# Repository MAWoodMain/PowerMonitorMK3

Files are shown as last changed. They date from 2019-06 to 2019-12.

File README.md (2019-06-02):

# Power Meter MK3

## The Plan

The plan is to evaluate the ADE9153 IC using an initial PCB build with mains isolation for easy development and no real planned form factor.

Then assuming the IC checks out the schematic and PCB will be reissued without isolation and with a much tigher form factor to fit in a DIN rail enclosure so it can be wired into my home.

An extra prototype run may be required inbetween to evaluate isolation removal or to fix mistakes that render ISS1 unusable.

The ISS1 PCB is powered from the safe side using a micro USB cable and this power is isolated and used on the hot side, this circuit is based on the ADE9153's evaluation board schematic. 

**It is noteworthy that the hot side's GND is mains live and does present a serious safety risk.**

I accept no liability for anyone else's use of this design.

## PCB Builds

### ISS1 Build:
- PCB ordered from JLC PCB
  - ENIG finish
  - 1.6mm FR4
  - Top side stencil order with the PCB
    - Ordered default size, this was a mistake next time order a custom side much smaller
- Parts ordered from LCSC and DigiKey kitting for 2 PCBs
  - DHL on behalf of Digikey charged excessive customs charges inflating the build cost greatly I recommend Mouser as an alternative (for the UK) and have upissued the BOM accordingly
- Assembled at home
  - Boards were cleaned with IPA
  - Scrap PCBs were used to position the new PCB in place for stenciling
  - Paste was squeegeed onto the boards using a scrap piece of ceramic with a very flat edge
  - All components were hand placed with tweezers
  - The board was placed on a temperature controlled hotplate at 150°C
  - Once the board was evenly preheated (confirmed with IR thermometer) 350°C hot air was used to reflow the components
  - Some joints were not fully reflowed so touchups were performed with a fine soldering tip and extra liquid flux
  - The ADE9153 IC is in a QFN package which is difficult to manage as a hobbiest so reflow did yield some shorts on the edges, the shorts were manually reworked with extra flux and a fine tip.
  - Fortunatly the guard trace around the VAMS did not short to GND or VAMS, the layout recommendations from AD were to expose copper under the QFN which posed a high risk of soldering shorts.
  - The board was then cleaned with flux clean and IPA
  - All hand soldered components were soldered normally
  - A final clean was performed with flux clean
  
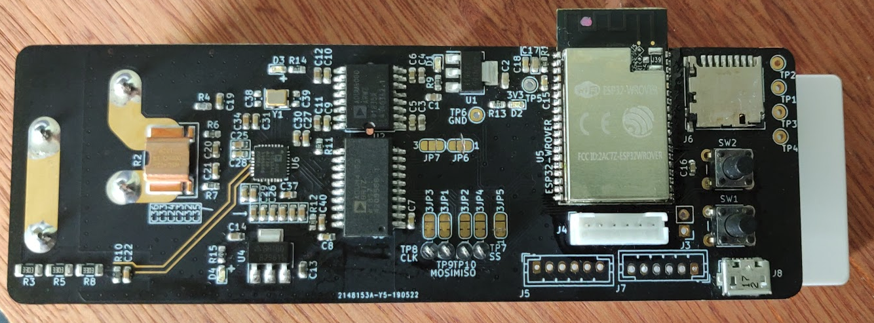
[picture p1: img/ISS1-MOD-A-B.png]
ISS1 Build


#### Issues associated with this build:
[#1](/../../issues/1) [#2](/../../issues/2) [#3](/../../issues/3)
#### Board mods:
- **MOD A** 
  - Pin 5 of U2 (Isolated DC-DC) has to be isolated, the PCB connects it to GND which prevents the IC from working
     - I cut the leg off the IC to isolate it

- **MOD B** 
  - ESP32-Wrover pins 17-22 cannot be used as they are used internally
     - I cut NC jumpers JP5, JP6 & JP7, the both sides of all three jumpers is reserved for internal use so manual wire mods will be needed lated to connect these to appropriate pins

## Firmware development

Currently in hardware testing phase, temporary non VCS projects are being used to evaluate the PCB, once this process is complete a formal firmware project will be added to VCS and developed

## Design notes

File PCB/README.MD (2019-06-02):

# Power Monitor MK3 PCB

## Outstanding Issues

- [ ] [#1](/../../issues/1) Copper pour sticks out of board edge
- [ ] [#2](/../../issues/2) U2's Pin 5 shorted to GND should be NC
- [ ] [#3](/../../issues/3) Reserved pins being used on JP5, JP6 & JP7
- [ ] Silkscreen is uninformative
- [ ] Power LEDs on all rails is annoying and not very useful after the initial power on test
- [ ] No LED to blink from the ESP?
- [ ] No test points on the mains side (was intentional because GND is 240Vac over there :grimacing:)
- [ ] Add CH340G or equivilent USB to UART with auto GPIO0 & RST for toolless development

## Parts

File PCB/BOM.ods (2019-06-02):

Reference | Quantity | Value | Footprint | Already Have | Supplier | PN & link | Mfr PN | Price/unit @ Q | MOQ | Total price | Cost
C11 C4 C3 C12 C13 C1 | 6 | 10uF | Capacitor_SMD:C_0603_1608Metric | NO | LCSC | C92487 (https://lcsc.com/product-detail/Multilayer-Ceramic-Capacitors-MLCC-SMD-SMT_SAMSUNG_CL10A106MO8NQNC_10uF-106-20-16V_C92487.html) | CL10A106MO8NQNC | $0.0340 | 10 | $0.34 | $0.34
C14 C2 C17 | 3 | 22uF | Capacitor_SMD:C_0603_1608Metric | NO | LCSC | C86295 (https://lcsc.com/product-detail/Multilayer-Ceramic-Capacitors-MLCC-SMD-SMT_SAMSUNG_CL10A226MP8NUNE_22uF-226-20-10V_C86295.html) | CL10A226MP8NUNE | $0.0230 | 20 | $0.46 | $0.46
C22 | 1 | 15nF | Capacitor_SMD:C_0603_1608Metric | NO | LCSC | C296713 (https://lcsc.com/product-detail/Others_Samsung-Electro-Mechanics_CL10B153KB8NNNC_Samsung-Electro-Mechanics-CL10B153KB8NNNC_C296713.html) | CL10B153KB8NNNC | $0.0058 | 50 | $0.29 | $0.29
C36 C35 C27 C34 C26 C25 C23 | 7 | 4.7uF | Capacitor_SMD:C_0603_1608Metric | NO | LCSC | C69335 (https://lcsc.com/product-detail/Multilayer-Ceramic-Capacitors-MLCC-SMD-SMT_SAMSUNG_CL10A475KA8NQNC_4-7uF-475-10-25V_C69335.html) | CL10A475KA8NQNC | $0.0303 | 20 | $0.61 | $0.61
C37 | 1 | 470nF | Capacitor_SMD:C_0603_1608Metric | NO | LCSC | C318652 (https://lcsc.com/product-detail/Others_Samsung-Electro-Mechanics_CL10F474ZO8NNNC_Samsung-Electro-Mechanics-CL10F474ZO8NNNC_C318652.html) | CL10F474ZO8NNNC | $0.0081 | 50 | $0.41 | $0.41
C39 C38 | 2 | 30pF | Capacitor_SMD:C_0603_1608Metric | NO | LCSC | C22397 (https://lcsc.com/product-detail/Multilayer-Ceramic-Capacitors-MLCC-SMD-SMT_SAMSUNG_CL10C300JB8NNNC_30pF-300-5-50V_C22397.html) | CL10C300JB8NNNC | $0.0053 | 50 | $0.27 | $0.27
C40 | 1 | 1uF | Capacitor_SMD:C_0603_1608Metric | NO | LCSC | C59782 (https://lcsc.com/product-detail/Multilayer-Ceramic-Capacitors-MLCC-SMD-SMT_SAMSUNG_CL10B105KO8NNNC_1uF-105-10-16V_C59782.html) | CL10B105KO8NNNC | $0.0065 | 50 | $0.33 | $0.33
C9 C6 C5 C10 C7 C8 C18 C15 C16 C33 C32 C31 C30 C29 C28 C20 C21 C19 C24 | 19 | 100nF | Capacitor_SMD:C_0603_1608Metric | NO | LCSC | C1590 (https://lcsc.com/product-detail/Multilayer-Ceramic-Capacitors-MLCC-SMD-SMT_SAMSUNG_CL10B104KA8NNNC_100nF-104-10-25V_C1590.html) | CL10B104KA8NNNC | $0.0057 | 50 | $0.29 | $0.29
D4 D3 D2 D1 | 4 | LED | LED_SMD:LED_0603_1608Metric | NO | LCSC | C205443 (https://lcsc.com/product-detail/Light-Emitting-Diodes-LED_0603-green_C205443.html) | ORH-G36G | $0.0096 | 50 | $0.48 | $0.48
J1 J2 | 2 | MAINS_OUT & MAINS_IN | 1792229:PHOENIX_1792229 | NO | Mouser | 651-1792229 (https://www.mouser.co.uk/ProductDetail/Phoenix-Contact/1792229) | 1792229 | $4.2600 | 1 | $8.52 | $8.52
J3 | 1 | ESP32_BOOT | Connector_PinHeader_2.54mm:PinHeader_1x02_P2.54mm_Vertical | YES | LCSC | C132504 (https://lcsc.com/product-detail/Wire-To-Board-Wire-To-Wire-Connector_Shenzhen-Cankemeng-2510S-2P_C132504.html) | 2510S-2P | $0.0102 | 50 | $0.51 | $0.00
J5 J4 J7 | 2 | ESP_JTAG | Connector_JST:JST_PH_B6B-PH-K_1x06_P2.00mm_Vertical | NO | LCSC | C33478 (https://lcsc.com/product-detail/Wire-To-Board-Wire-To-Wire-Connector_Boom-Precision-Elec-PH-6A_C33478.html) | PH-6A | $0.0105 | 50 | $0.53 | $0.53
J6 | 1 | Micro_SD_Card | Connector_Card:microSD_HC_Hirose_DM3D-SF | NO | Mouser | 798-DM3D-SF (https://www.mouser.co.uk/ProductDetail/Hirose-Connector/DM3D-SF) | DM3D-SF | $1.5300 | 1 | $1.53 | $1.53
J8 | 1 | USB_B_Micro | Connector_USB:USB_Micro-B_Molex_47346-0001 | NO | LCSC | C132560 (https://lcsc.com/product-detail/USB-Connectors_MOLEX_47346-0001_47346-0001_C132560.html) | 47346-0001 | $0.8320 | 1 | $0.83 | $0.83
R1 | 1 | 100K | Resistor_SMD:R_0603_1608Metric | NO | LCSC | C25803 (https://lcsc.com/product-detail/Chip-Resistor-Surface-Mount_Uniroyal-Elec-0603WAF1003T5E_C25803.html) | 0603WAF1003T5E | $0.0010 | 100 | $0.10 | $0.10
R11 R12 | 2 | 10K | Resistor_SMD:R_0603_1608Metric | NO | LCSC | C25804 (https://lcsc.com/product-detail/Chip-Resistor-Surface-Mount_Uniroyal-Elec-0603WAF1002T5E_C25804.html) | 0603WAF1002T5E | $0.0010 | 100 | $0.10 | $0.10
R14 R9 R10 | 3 | 1K | Resistor_SMD:R_0603_1608Metric | NO | LCSC | C21190 (https://lcsc.com/product-detail/Chip-Resistor-Surface-Mount_Uniroyal-Elec-0603WAF1001T5E_C21190.html) | 0603WAF1001T5E | $0.0008 | 100 | $0.08 | $0.08
R15 R13 | 2 | 220 | Resistor_SMD:R_0603_1608Metric | NO | LCSC | C107696 (https://lcsc.com/product-detail/Chip-Resistor-Surface-Mount_220R-220R-1_C107696.html) | RC0603FR-07220RL | $0.0009 | 100 | $0.09 | $0.09
R2 | 1 | 300u/500u | Project:WSL4026 | NO | Mouser | 71-WSL4026L5000FEB (https://www.mouser.co.uk/ProductDetail/Vishay-Dale/WSL4026L5000FEB) | WSL4026L5000FEB | $2.1700 | 1 | $2.17 | $2.17
R3 R5 R8 | 3 | 330K | Resistor_SMD:R_1206_3216Metric | NO | LCSC | C163390 (https://lcsc.com/product-detail/Chip-Resistor-Surface-Mount_RC1206DR-07330KL_C163390.html) | RC1206DR-07330KL | $0.0112 | 50 | $0.56 | $0.56
R4 | 1 | 0 | Resistor_SMD:R_0603_1608Metric | NO | LCSC | C163836 (https://lcsc.com/product-detail/Chip-Resistor-Surface-Mount_Walsin-Tech-Corp-WR06X0000FTL_C163836.html) | WR06X0000FTL | $0.0008 | 100 | $0.08 | $0.08
R6 R7 | 2 | 150K | Resistor_SMD:R_0603_1608Metric | NO | LCSC | C294649 (https://lcsc.com/product-detail/Others_Guangdong-Fenghua-Advanced-Tech-RS-03K1503FT_C294649.html) | RS-03K1503FT | $0.0010 | 100 | $0.10 | $0.10
SW1 SW2 | 1 | BOOT_SW | Button_Switch_THT:SW_PUSH_6mm | YES | LCSC | C294501 (https://lcsc.com/product-detail/Tactile-Switches_BRIGHT-TSA061G50-250_C294501.html) | TSA061G50-250 | $0.0193 | 20 | $0.39 | $0.00
TP1 TP2 TP3 TP4 TP5 TP6 TP7 TP8 TP9 TP10 | 10 | Several | Connector_Pin:Pin_D1.0mm_L10.0mm | NO | LCSC | C238122 (https://lcsc.com/product-detail/Test-Points-Test-Rings_Keystone_5001_Keystone-5001_C238122.html) | 5001 | $0.2402 | 1 | $2.40 | $2.40
U2 | 1 | ADuM6000 | Package_SO:SOIC-16W_7.5x10.3mm_P1.27mm | NO | Mouser | 584-ADUM6000ARWZ (https://www.mouser.co.uk/ProductDetail/Analog-Devices-Linear-Technology/ADUM6000ARWZ) | ADUM6000ARWZ | $8.6100 | 1 | $8.61 | $8.61
U3 | 1 | ADuM4152BRIZ | Package_SO:SOIC-20W_7.5x12.8mm_P1.27mm | NO | Mouser | 584-ADUM4152BRIZ (https://www.mouser.co.uk/ProductDetail/Analog-Devices/ADUM4152BRIZ) | ADUM4152BRIZ | $9.4800 | 1 | $9.48 | $9.48
U4 U1 | 2 | AZ1117-3.3 | Package_TO_SOT_SMD:SOT-223-3_TabPin2 | NO | LCSC | C92102 (https://lcsc.com/product-detail/Low-Dropout-Regulators-LDO_DIODES_AZ1117CH-3-3TRG1_AZ1117CH-3-3TRG1_C92102.html) | AZ1117CH-3.3TRG1 | $0.0677 | 5 | $0.34 | $0.34
U5 | 1 | ESP32-WROVER-B_(16MB) | ESP32-WROVER-B__16MB_:XCVR_ESP32-WROVER-B_(16MB) | NO | Mouser | 356-ESP32-WROB(16MB) (https://www.mouser.co.uk/ProductDetail/Espressif-Systems/ESP32-WROVER-B-16MB) | ESP32-WROVER (16MB) | $4.8300 | 1 | $4.83 | $4.83
U6 | 1 | ADE9153A | Package_DFN_QFN:QFN-32-1EP_5x5mm_P0.5mm_EP3.1x3.1mm | NO | Mouser | 584-ADE9153AACPZ (https://www.mouser.co.uk/ProductDetail/Analog-Devices/ADE9153AACPZ) | ADE9153AACPZ | $6.3800 | 1 | $6.38 | $6.38
Y1 | 1 | 12.288MHz 18pF | Crystal:Crystal_SMD_3225-4Pin_3.2x2.5mm | NO | LCSC | C24117 (https://lcsc.com/product-detail/SMD-Oscillators-XO_EPSON_Q33310F70062000_SG-310SCF-12-288MHZ-3-3V-40-85_C24117.html) | Q33310F70062000 | $0.6968 | 1 | $0.70 | $0.70
 |  |  |  |  |  |  |  |  |  | $51.78 | $50.88

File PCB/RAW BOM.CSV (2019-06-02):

Reference | Quantity | Value | Footprint | Datasheet | Field4 | Field5 | Field6 | Field7 | Field8
C11 C4 C3 C12 C13 C1 | 6 | 10uF | Capacitor_SMD:C_0603_1608Metric | ~
C14 C2 C17 | 3 | 22uF | Capacitor_SMD:C_0603_1608Metric | ~
C22 | 1 | 15nF | Capacitor_SMD:C_0603_1608Metric | ~
C36 C35 C27 C34 C26 C25 C23 | 7 | 4.7uF | Capacitor_SMD:C_0603_1608Metric | ~
C37 | 1 | 470nF | Capacitor_SMD:C_0603_1608Metric | ~
C39 C38 | 2 | 30pF | Capacitor_SMD:C_0603_1608Metric | ~
C40 | 1 | 1uF | Capacitor_SMD:C_0603_1608Metric | ~
C9 C6 C5 C10 C7 C8 C18 C15 C16 C33 C32 C31 C30 C29 C28 C20 C21 C19 C24 | 19 | 100nF | Capacitor_SMD:C_0603_1608Metric | ~
D4 D3 D2 D1 | 4 | LED | LED_SMD:LED_0603_1608Metric | ~
J1 | 1 | MAINS_OUT | 1792229:PHOENIX_1792229 | ~
J2 | 1 | MAINS_IN | 1792229:PHOENIX_1792229 | ~
J3 | 1 | ESP32_BOOT | Connector_PinHeader_2.54mm:PinHeader_1x02_P2.54mm_Vertical | ~
J5 J4 | 2 | ESP_JTAG | Connector_JST:JST_PH_B6B-PH-K_1x06_P2.00mm_Vertical | ~
J6 | 1 | Micro_SD_Card | Connector_Card:microSD_HC_Hirose_DM3D-SF | http://katalog.we-online.de/em/datasheet/693072010801.pdf
J7 | 1 | ESP_EINK | Connector_JST:JST_PH_B6B-PH-K_1x06_P2.00mm_Vertical | ~
J8 | 1 | USB_B_Micro | Connector_USB:USB_Micro-B_Molex_47346-0001 | ~
JP1 JP5 JP6 JP7 | 4 | MOSI_SEL | Jumper:SolderJumper-3_P1.3mm_Bridged12_RoundedPad1.0x1.5mm_NumberLabels | ~
JP2 | 1 | MISO_SEL | Jumper:SolderJumper-3_P1.3mm_Bridged12_RoundedPad1.0x1.5mm_NumberLabels | ~
JP3 | 1 | SCLK_SEL | Jumper:SolderJumper-3_P1.3mm_Bridged12_RoundedPad1.0x1.5mm_NumberLabels | ~
JP4 | 1 | SS_SEL | Jumper:SolderJumper-3_P1.3mm_Bridged12_RoundedPad1.0x1.5mm_NumberLabels | ~
R1 | 1 | 100K | Resistor_SMD:R_0603_1608Metric | ~
R11 R12 | 2 | 10K | Resistor_SMD:R_0603_1608Metric | ~
R14 R9 R10 | 3 | 1K | Resistor_SMD:R_0603_1608Metric | ~
R15 R13 | 2 | 220 | Resistor_SMD:R_0603_1608Metric | ~
R2 | 1 | 300u | Project:WSL4026 | ~
R3 R5 R8 | 3 | 330K | Resistor_SMD:R_1206_3216Metric | ~
R4 | 1 | 0 | Resistor_SMD:R_0603_1608Metric | ~
R6 R7 | 2 | 150K | Resistor_SMD:R_0603_1608Metric | ~
SW1 | 1 | BOOT_SW | Button_Switch_THT:SW_PUSH_6mm | ~
SW2 | 1 | RST_SW | Button_Switch_THT:SW_PUSH_6mm | ~
TP1 | 1 | hSS | Connector_Pin:Pin_D1.0mm_L10.0mm | ~
TP10 | 1 | vMISO | Connector_Pin:Pin_D1.0mm_L10.0mm | ~
TP2 | 1 | hSCLK | Connector_Pin:Pin_D1.0mm_L10.0mm | ~
TP3 | 1 | hMOSI | Connector_Pin:Pin_D1.0mm_L10.0mm | ~
TP4 | 1 | hMISO | Connector_Pin:Pin_D1.0mm_L10.0mm | ~
TP5 | 1 | 3V3 | Connector_Pin:Pin_D1.0mm_L10.0mm | ~
TP6 | 1 | GND | Connector_Pin:Pin_D1.0mm_L10.0mm | ~
TP7 | 1 | vSS | Connector_Pin:Pin_D1.0mm_L10.0mm | ~
TP8 | 1 | vSCLK | Connector_Pin:Pin_D1.0mm_L10.0mm | ~
TP9 | 1 | vMOSI | Connector_Pin:Pin_D1.0mm_L10.0mm | ~
U2 | 1 | ADuM6000 | Package_SO:SOIC-16W_7.5x10.3mm_P1.27mm | https://www.analog.com/media/en/technical-documentation/data-sheets/ADuM6000.PDF
U3 | 1 | ADuM4152BRIZ | Package_SO:SOIC-20W_7.5x12.8mm_P1.27mm | https://www.analog.com/media/en/technical-documentation/data-sheets/ADuM4151_4152_4153.pdf
U4 U1 | 2 | AZ1117-3.3 | Package_TO_SOT_SMD:SOT-223-3_TabPin2 | https://www.diodes.com/assets/Datasheets/AZ1117.pdf
U5 | 1 | ESP32-WROVER-B_(16MB) | ESP32-WROVER-B__16MB_:XCVR_ESP32-WROVER-B_(16MB) |  | Unavailable | Espressif Systems | None | None | ESP32-WROVER-B _16MB_
U6 | 1 | ADE9153A | Package_DFN_QFN:QFN-32-1EP_5x5mm_P0.5mm_EP3.1x3.1mm
Y1 | 1 | 12.288MHz 18pF | Crystal:Crystal_SMD_3225-4Pin_3.2x2.5mm | ~

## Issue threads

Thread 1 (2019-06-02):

Copper pour extends to board edge

MAWoodMain, 2019-06-02:
JLC PCB flagged the minor gerber error of my GND copper fill in the ESP half being exposed on the PCB edge because the fill continues all the way to the edge.

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

MAWoodMain, 2019-06-02:
This is very minor and can be resolved in ISS2

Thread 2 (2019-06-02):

Isolated DC-DC is not running

MAWoodMain, 2019-06-02:
On initial power up only the ESP side LEDs came on and a multimeter confirmed that the mains side did not have power and the rails were not shorted.

MAWoodMain, 2019-06-02:
Upon careful review of the schematic and datasheet an error was discovered Pin 5 of U2 is shorted to GND which is not a documented use case of the IC, MOD A is necessary to resolve this, isolate pin 5 and the chip starts working. Pending final resolution in the next PCB issue.

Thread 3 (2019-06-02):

ESP32 will not program via UART

MAWoodMain, 2019-06-02:
I connected the board to a usb FTDI lead using J4 and ESPtool.py was able to read details about the chip but when it can to programming the flash it just timed out.

MAWoodMain, 2019-06-02:
This is because certain GPIO on the ESP32-WRover module are used internally and as it turns out the IO I selected for ADE9153 RST, IRQ and CF2 are all used internally so should be avoided. This invalidates the default and alternative IO options for these three pins, the NC jumpers JP5,6&7 must be cut as per MOD B. A future mod will reconnect these to more appropriate IO.

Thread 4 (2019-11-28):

ADE IC not echoing SPI data

MAWoodMain, 2019-11-28:
When data is clocked out over MOSI the ADE is not being relayed over MISO as per the datasheet.

Conditions:
Forced into SPI mode using SS and SCLK on RST tested at 10KHz, 50KHz, 1MHz and 10MHz

MAWoodMain, 2019-11-28:
Issue with the ADE's crytal identified,

The crystal footprint is incorrecly pin-mapped and the fitted crystal is not a crystal its an integrated clock source...

Pending fix:

Remove incorrect part and solder replacement correct part on 45deg rotated so pins 1 & 3 lay across the footprint pads 1 & 2

MAWoodMain, 2019-12-02:
Trialed more appropriate crystal and wiring, but the IC still failed to operate, injected a clock source from a signal generator and the IC began functioning.
Resorted to using the integrated clock source
Seiko Epson Q33310F70062000

Wired with power and the clock out connected to the CLKIN pin of the ADE

At this point the ADE is functioning as expected

arigus, 2023-06-13:
crystal footprint is wrong. pins are should be diagonally

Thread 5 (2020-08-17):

How many Channel it can measure ?

asahajit, 2020-08-17:
How many channels it can measure?
Can we add WIFI.h Module for SSID and Password?
How it's performing in terms of accuracy?

MAWoodMain, 2020-08-17:
> How many channels it can measure?
> Can we add WIFI.h Module for SSID and Password?
> How it's performing in terms of accuracy?

Hi, this version of the design is single channel (voltage, current and power)

The firmware is non functional, unfortunately I had trouble with the development and moved on before it became too much of a time sink

The accuracy in theory is largely down to the ade IC, most of the other system error you should be able to calibrate out

Closed 2020-08-17.

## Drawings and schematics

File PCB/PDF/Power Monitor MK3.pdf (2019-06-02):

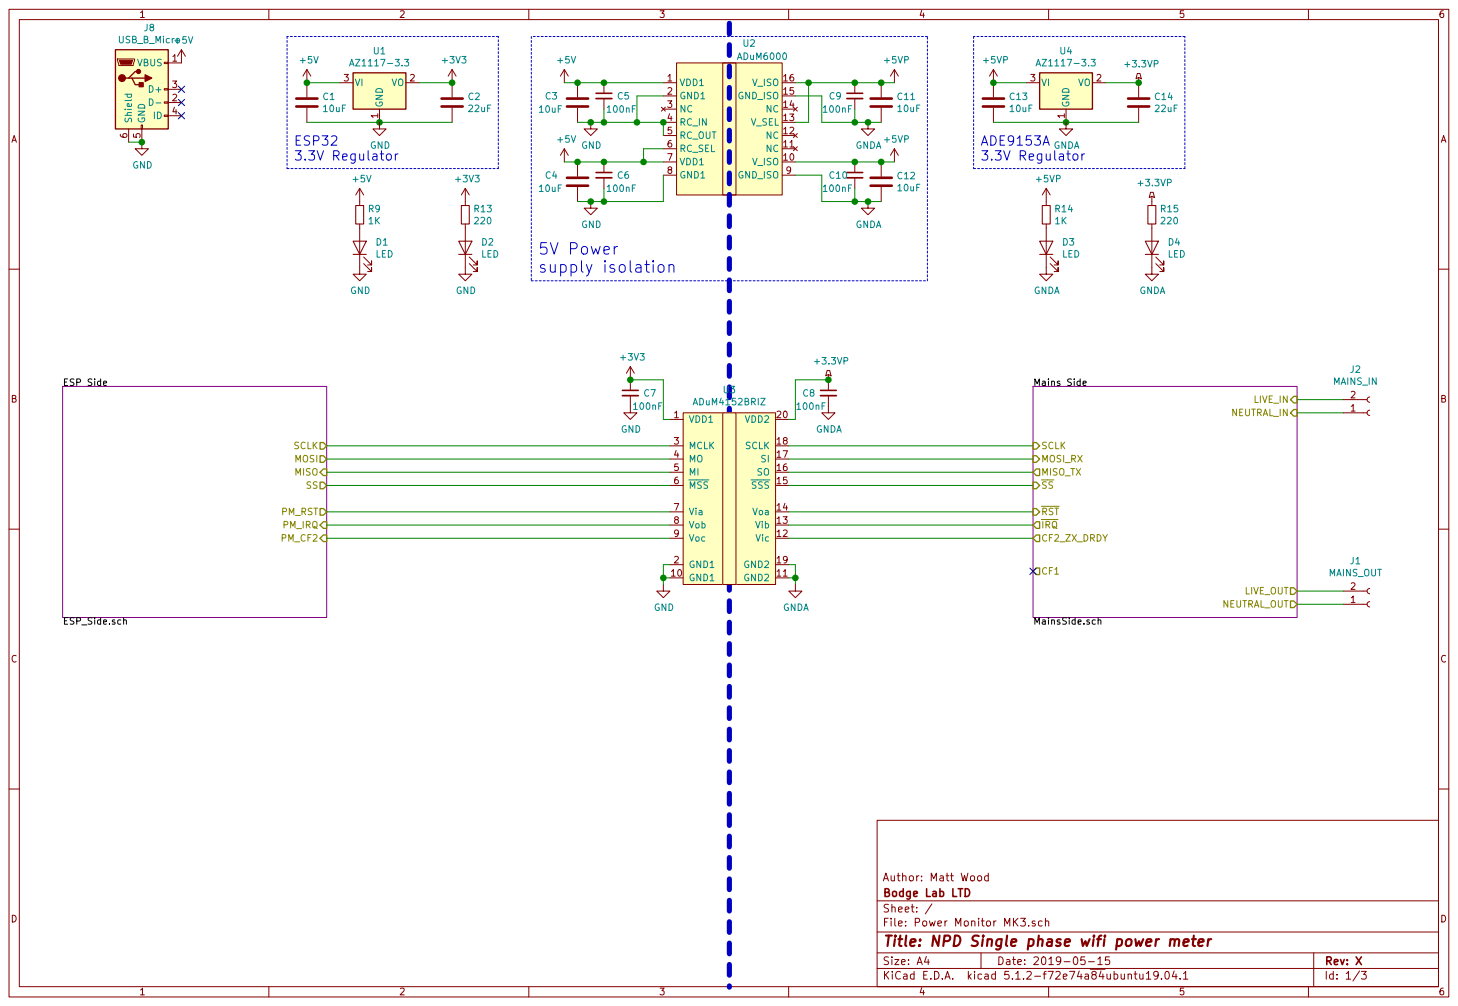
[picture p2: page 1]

Author: Matt Wood
Id: 1/3 Title: NPD Single phase wifi power meter File: Power Monitor MK3.sch Sheet: / Bodge Lab LTD

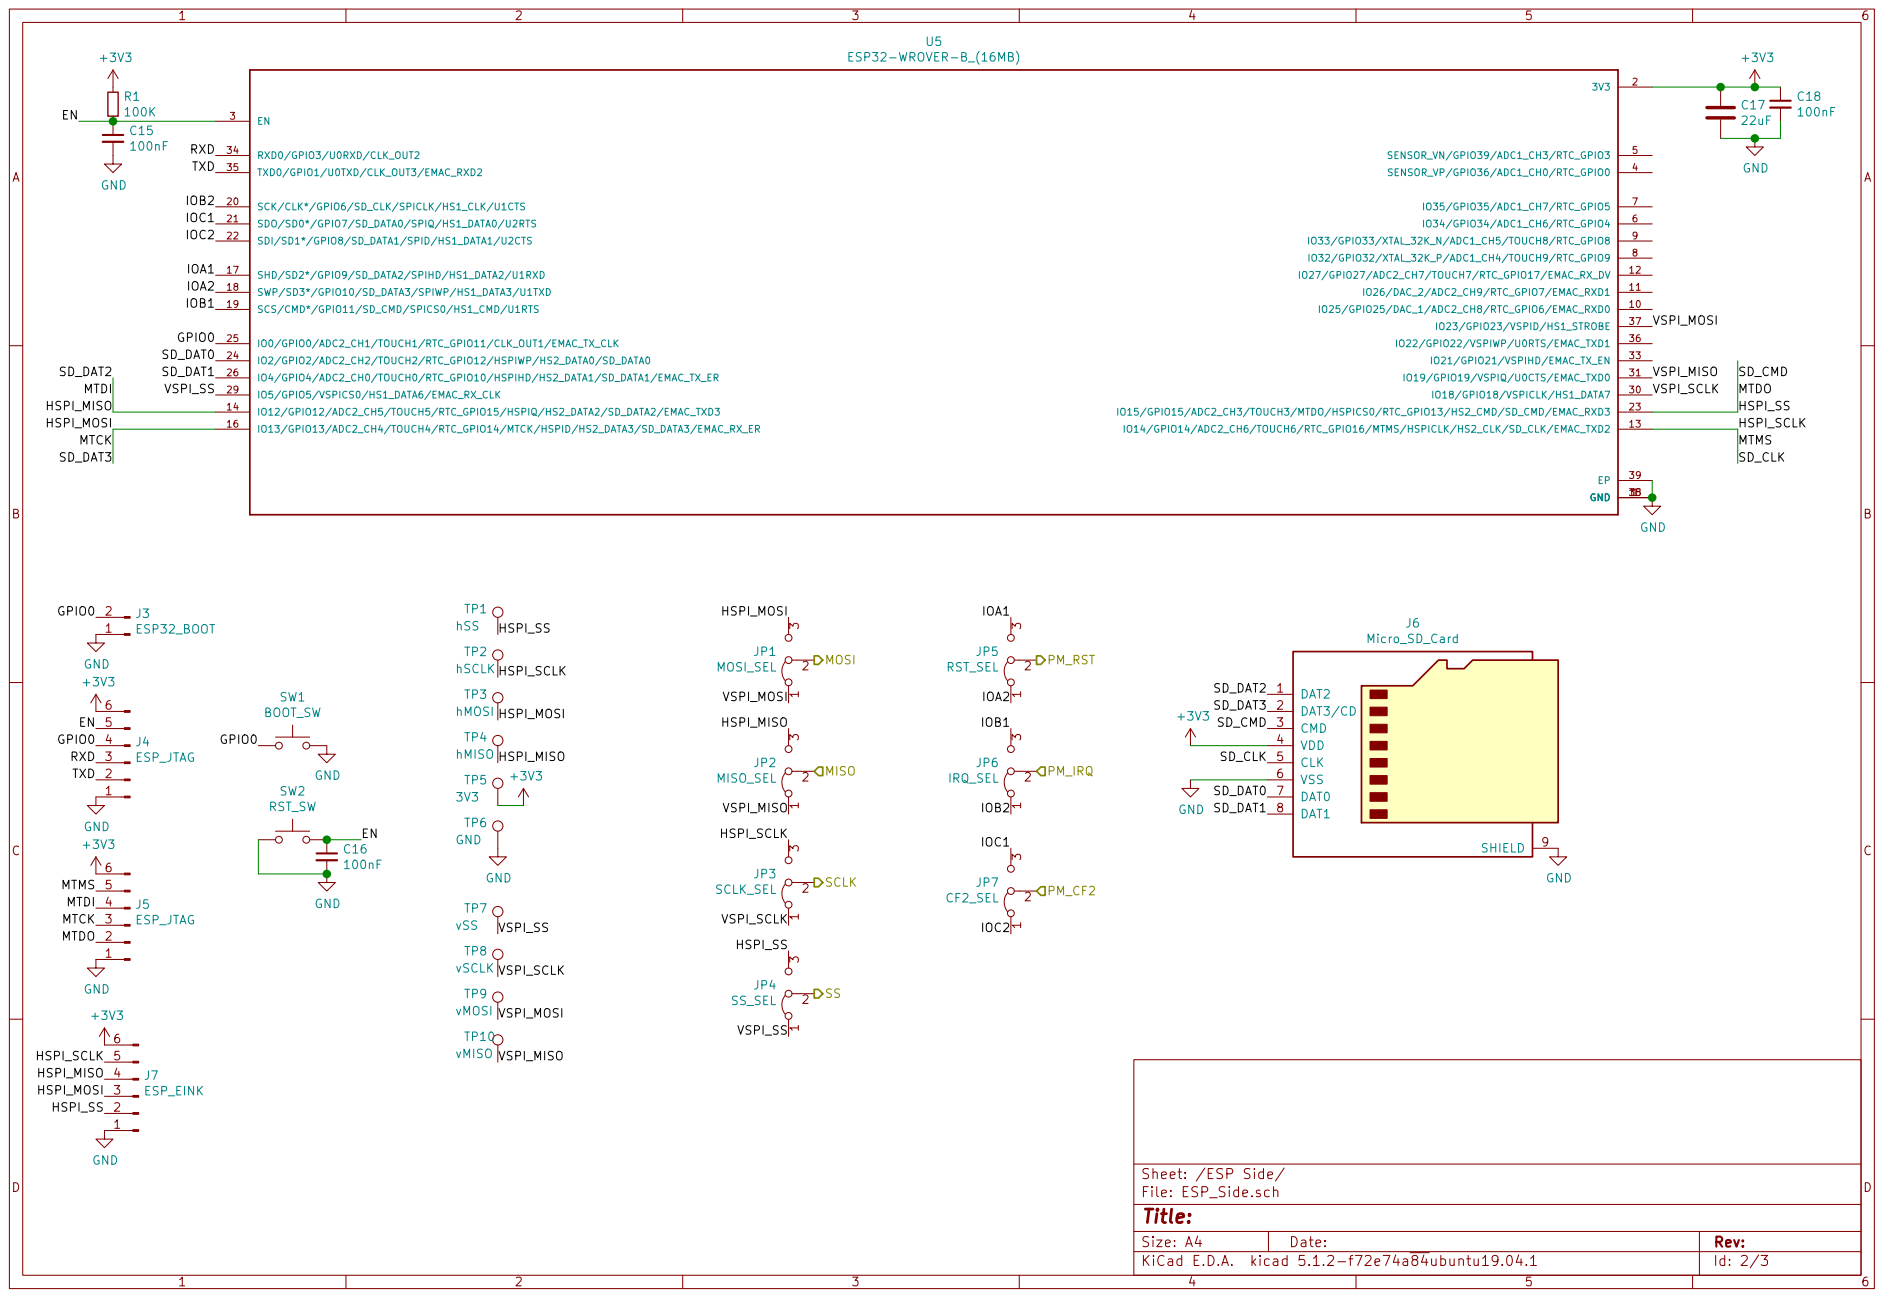
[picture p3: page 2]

GND MTDO MTCK MTDI MTMS

File: ESP_Side.sch Sheet: /ESP Side/
Id: 2/3 Title:

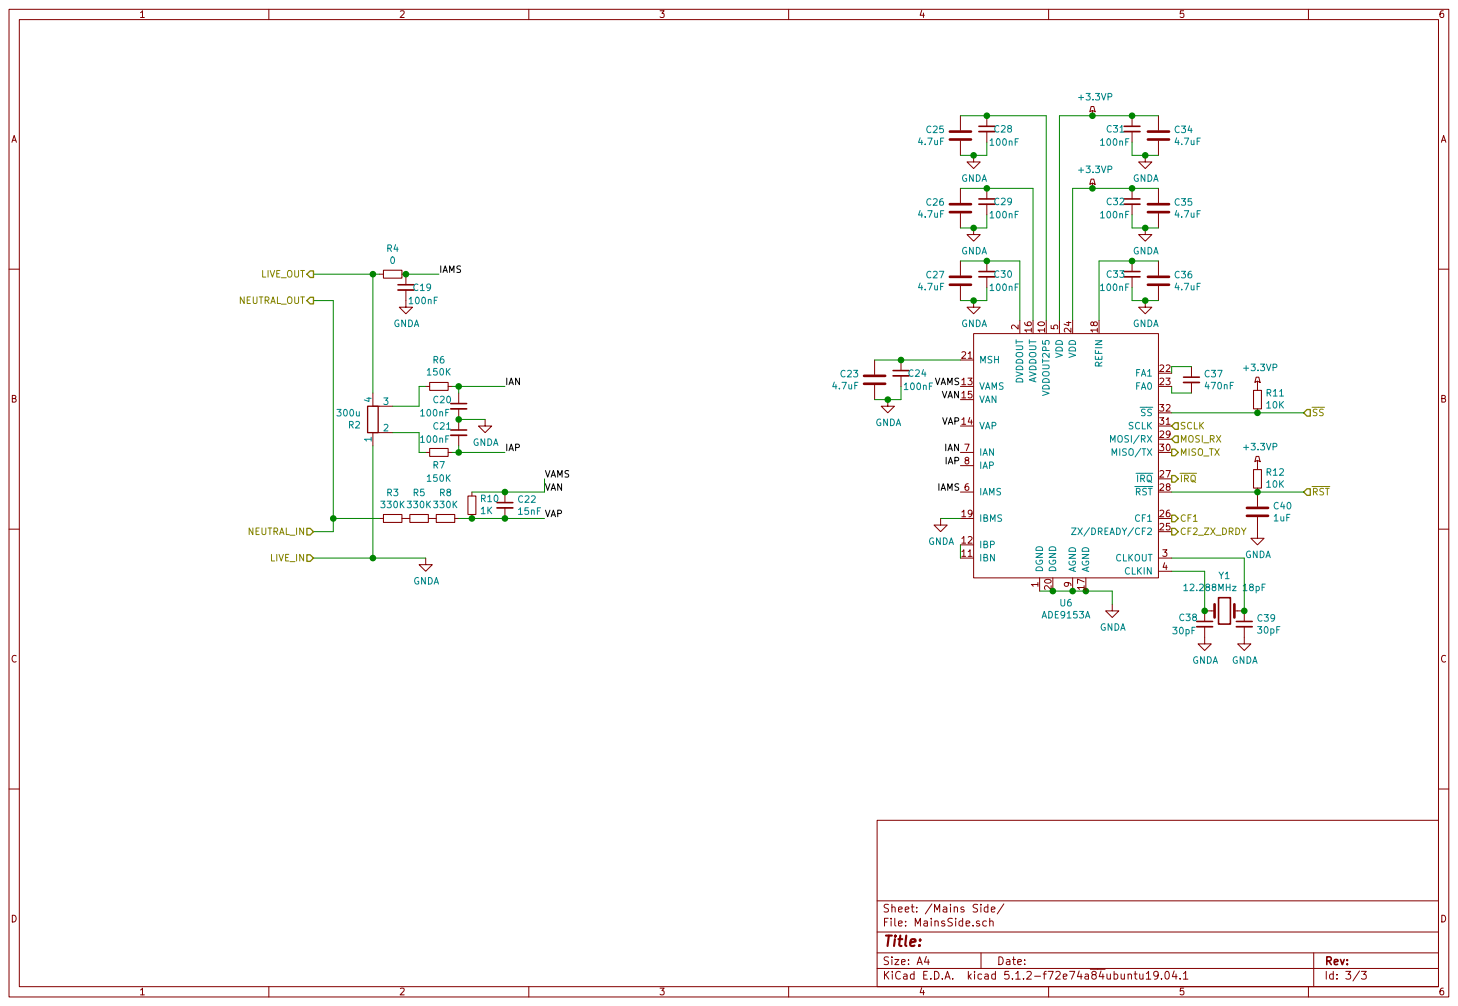
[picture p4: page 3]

2 DGND 20 MSH 21 FA1 22 FA0 23 VDD 24 ZX/DREADY/CF2 25 CF1 26

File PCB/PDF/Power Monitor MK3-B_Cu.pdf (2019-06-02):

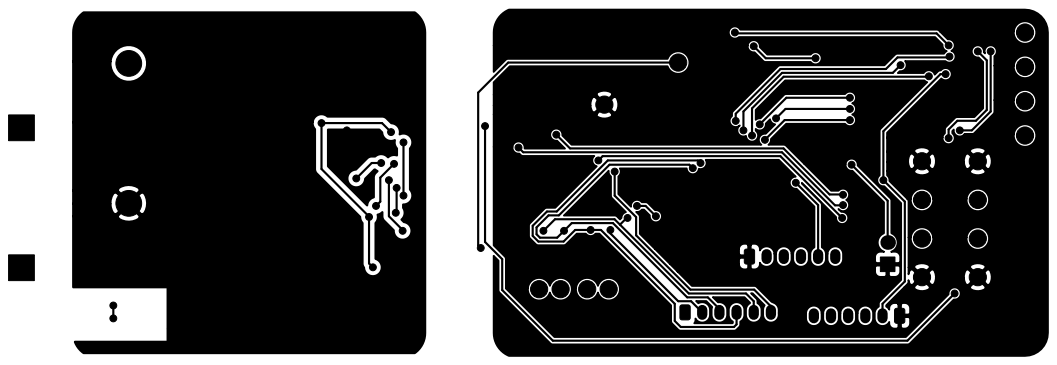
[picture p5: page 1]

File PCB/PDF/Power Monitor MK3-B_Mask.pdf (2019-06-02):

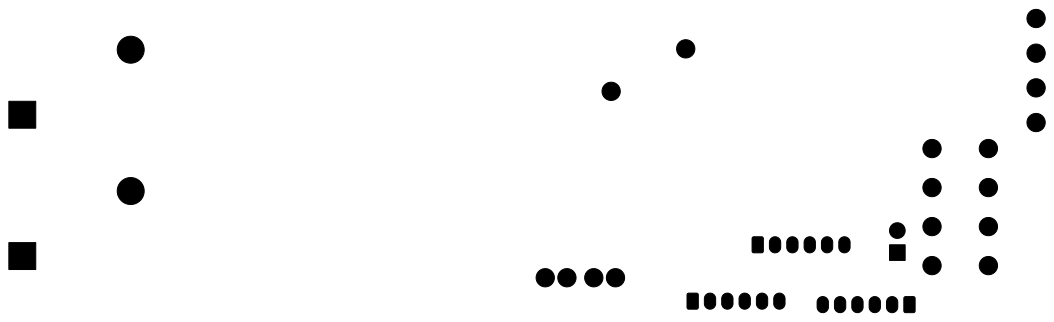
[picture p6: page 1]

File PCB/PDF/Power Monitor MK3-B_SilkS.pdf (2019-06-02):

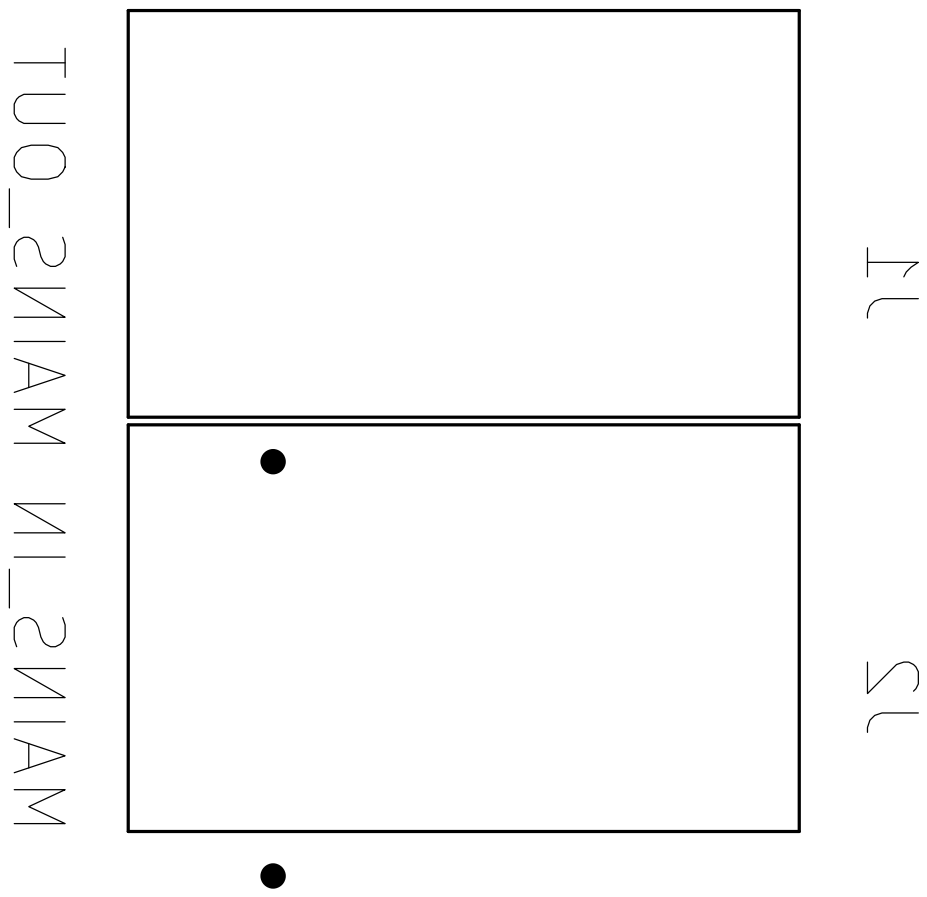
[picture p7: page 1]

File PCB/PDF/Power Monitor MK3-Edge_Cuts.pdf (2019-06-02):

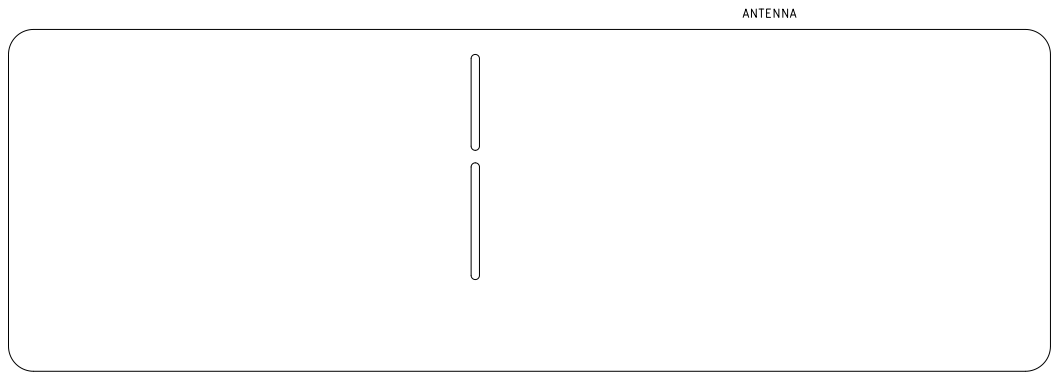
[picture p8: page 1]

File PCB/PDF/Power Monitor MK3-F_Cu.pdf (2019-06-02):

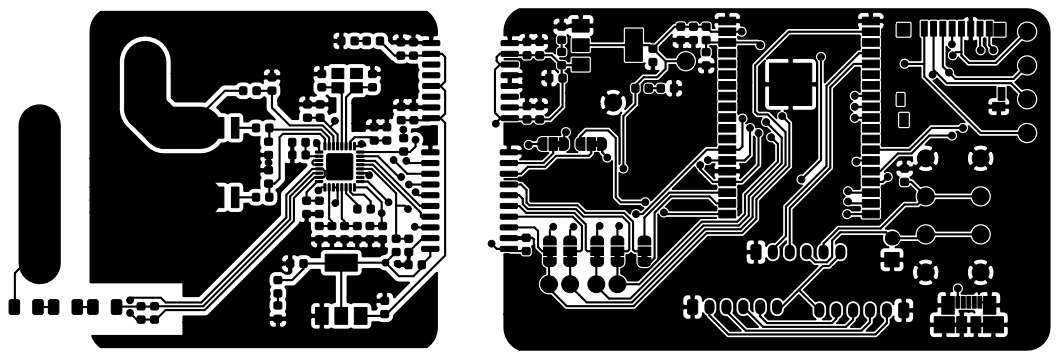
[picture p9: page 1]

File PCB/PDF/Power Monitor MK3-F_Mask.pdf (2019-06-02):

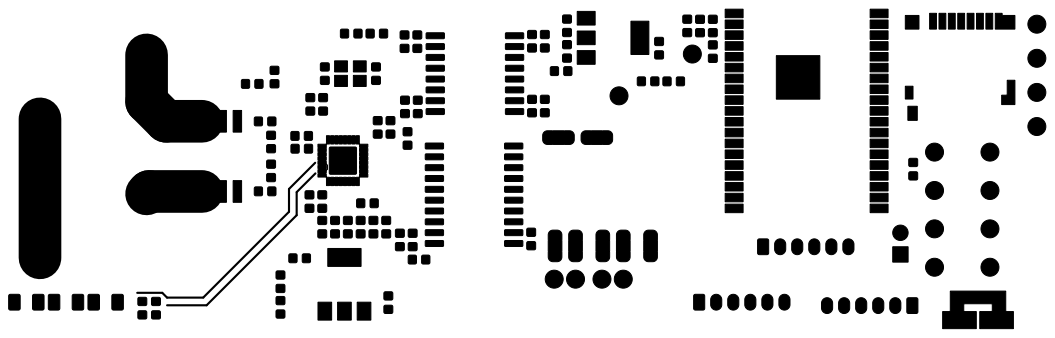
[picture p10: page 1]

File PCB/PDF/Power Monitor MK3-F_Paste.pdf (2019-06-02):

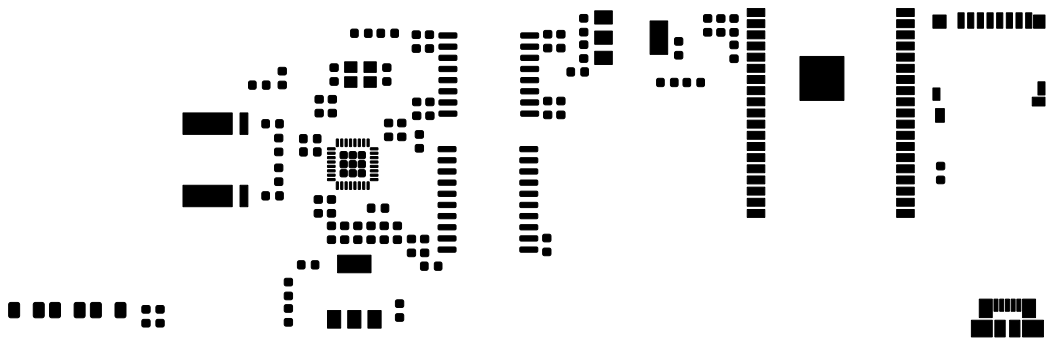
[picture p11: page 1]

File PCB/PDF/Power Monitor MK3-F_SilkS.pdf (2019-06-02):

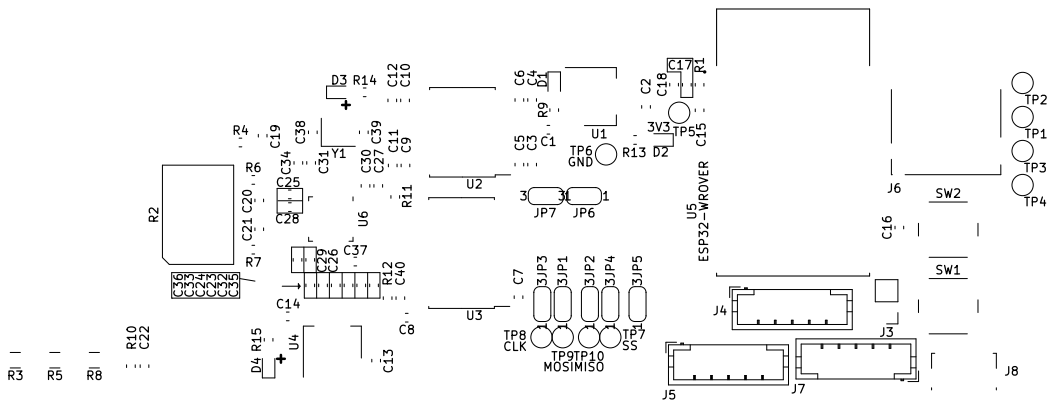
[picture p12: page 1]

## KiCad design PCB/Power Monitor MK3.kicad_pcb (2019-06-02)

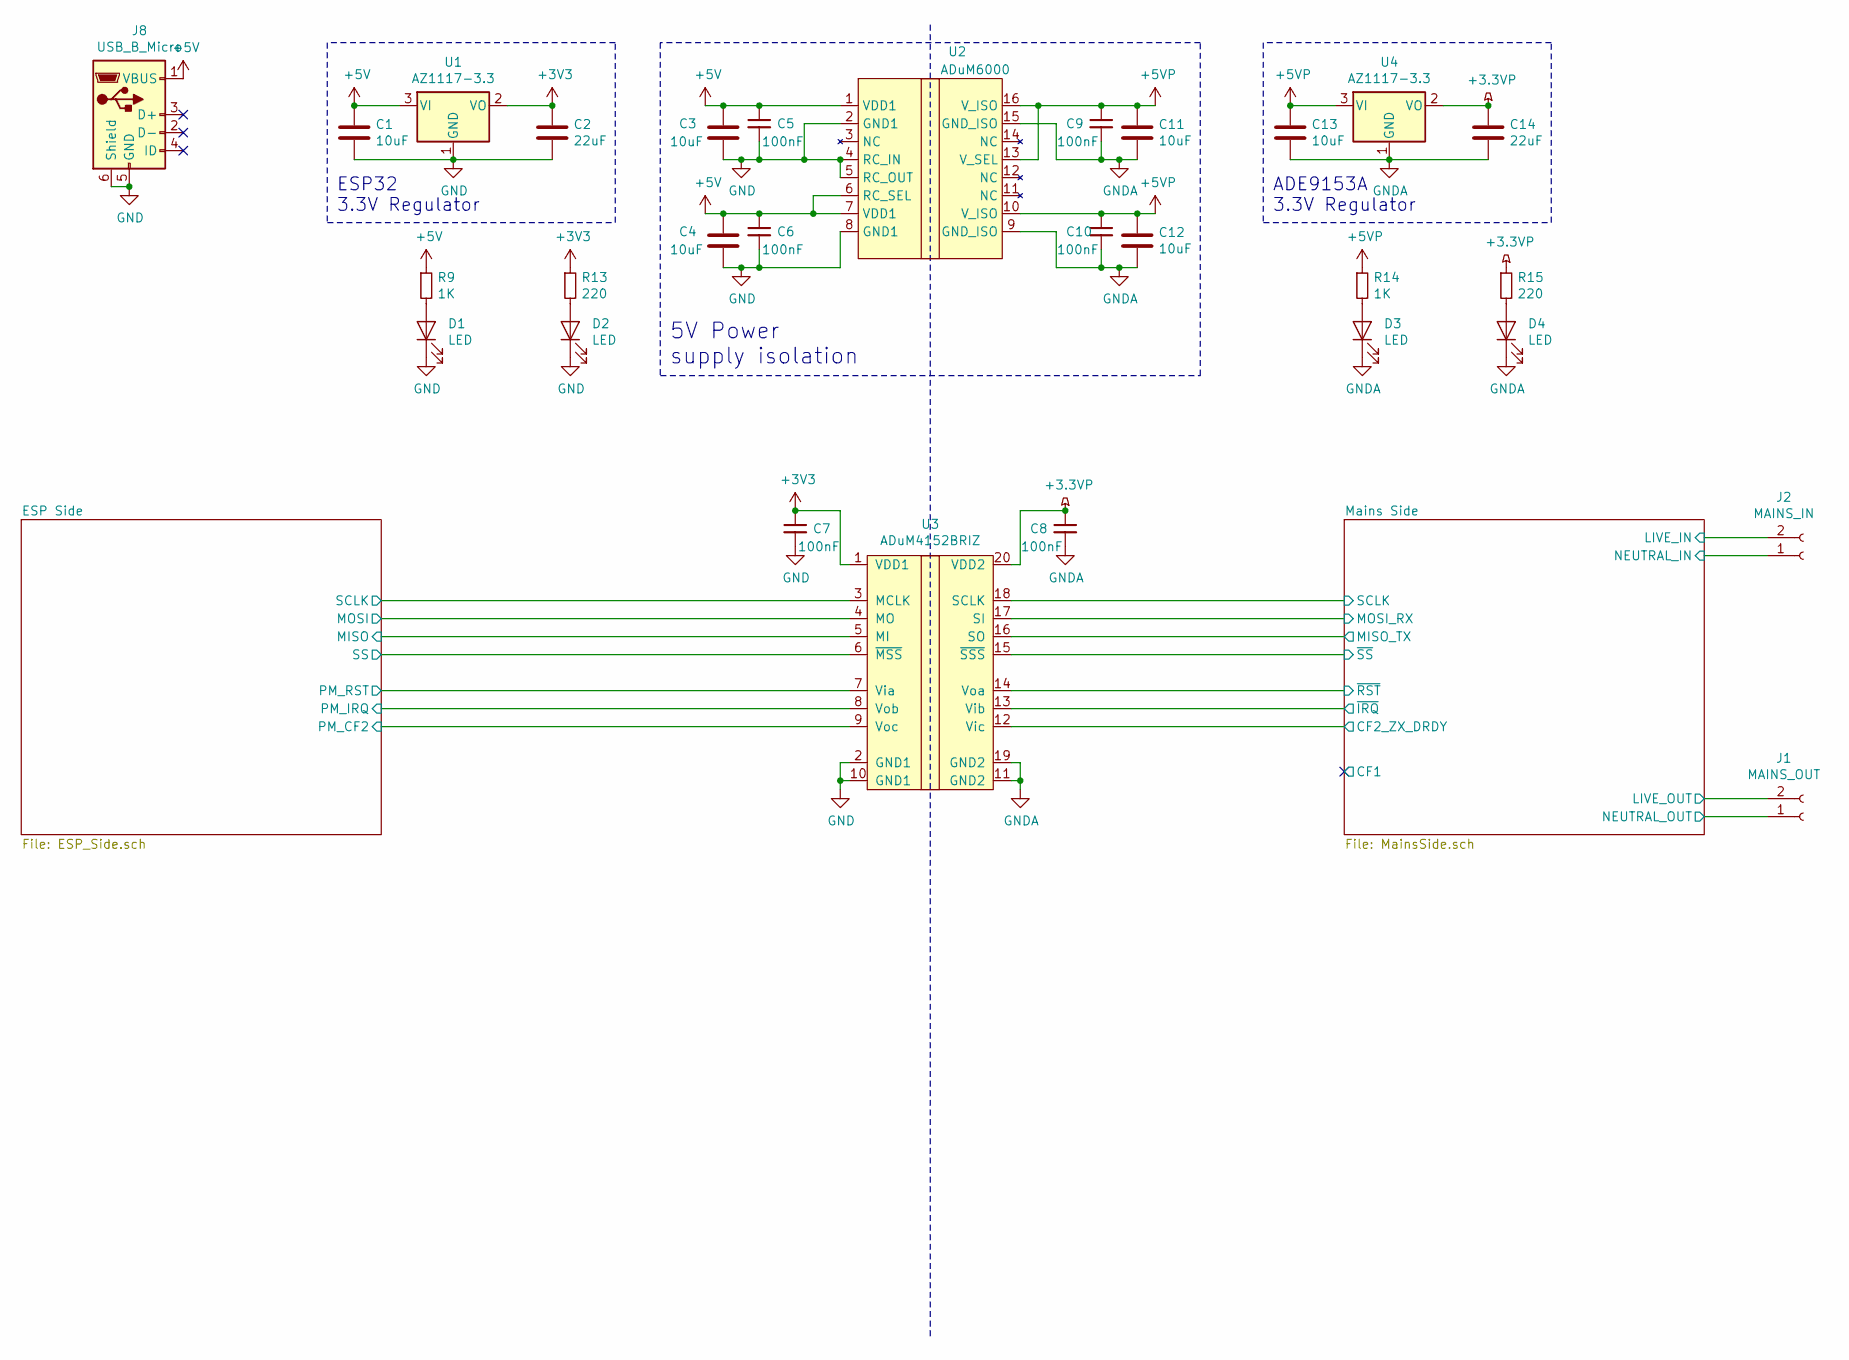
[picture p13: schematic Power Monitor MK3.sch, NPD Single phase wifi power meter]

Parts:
C1, C3, C4, C11, C12, C13: 10uF; C_0603_1608Metric
C2, C14: 22uF; C_0603_1608Metric
C5, C6, C7, C8, C9, C10: 100nF; C_0603_1608Metric
D1, D2, D3, D4: LED; LED_0603_1608Metric
J1: MAINS_OUT; PHOENIX_1792229
J2: MAINS_IN; PHOENIX_1792229
J8: USB_B_Micro; USB_Micro-B_Molex_47346-0001
R9, R14: 1K; R_0603_1608Metric
R13, R15: 220; R_0603_1608Metric
U1, U4: AZ1117-3.3; SOT-223-3_TabPin2
U2: ADuM6000; SOIC-16W_7.5x10.3mm_P1.27mm
U3: ADuM4152BRIZ; SOIC-20W_7.5x12.8mm_P1.27mm

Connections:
+3.3VP: C8.1, C14.1, R15.1, U3.20 (VDD2), U4.2 (VO); also elsewhere on the board
+3V3: C2.1, C7.1, R13.1, U1.2 (VO), U3.1 (VDD1); also elsewhere on the board
+5V: C1.1, C3.1, C4.1, C5.1, C6.1, J8.1 (VBUS), R9.1, U1.3 (VI), U2.1 (VDD1), U2.6 (RC_SEL), U2.7 (VDD1)
+5VP: C9.1, C10.1, C11.1, C12.1, C13.1, R14.1, U2.10 (V_ISO), U2.13 (V_SEL), U2.16 (V_ISO), U4.3 (VI)
/ESP Side/MISO: U3.5 (MI); also elsewhere on the board
/ESP Side/MOSI: U3.4 (MO); also elsewhere on the board
/ESP Side/PM_CF2: U3.9 (Voc); also elsewhere on the board
/ESP Side/PM_IRQ: U3.8 (Vob); also elsewhere on the board
/ESP Side/PM_RST: U3.7 (Via); also elsewhere on the board
/ESP Side/SCLK: U3.3 (MCLK); also elsewhere on the board
/ESP Side/SS: U3.6 (~MSS); also elsewhere on the board
/Mains Side/CF2_ZX_DRDY: U3.12 (Vic); also elsewhere on the board
/Mains Side/LIVE_OUT: J1.2; also elsewhere on the board
/Mains Side/MISO_TX: U3.16 (SO); also elsewhere on the board
/Mains Side/MOSI_RX: U3.17 (SI); also elsewhere on the board
/Mains Side/NEUTRAL_IN: J1.1, J2.1; also elsewhere on the board
/Mains Side/SCLK: U3.18 (SCLK); also elsewhere on the board
/Mains Side/~IRQ: U3.13 (Vib); also elsewhere on the board
/Mains Side/~RST: U3.14 (Voa); also elsewhere on the board
/Mains Side/~SS: U3.15 (~SSS); also elsewhere on the board
GND: C1.2, C2.2, C3.2, C4.2, C5.2, C6.2, C7.2, D1.1 (K), D2.1 (K), J8.5 (GND), J8.6 (Shield), U1.1 (GND), U2.2 (GND1), U2.4 (RC_IN), U2.5 (RC_OUT), U2.8 (GND1), U3.2 (GND1), U3.10 (GND1); also elsewhere on the board
GNDA: C8.2, C9.2, C10.2, C11.2, C12.2, C13.2, C14.2, D3.1 (K), D4.1 (K), J2.2, U2.9 (GND_ISO), U2.15 (GND_ISO), U3.11 (GND2), U3.19 (GND2), U4.1 (GND); also elsewhere on the board
unnamed: D1.2 (A), R9.2
unnamed: D2.2 (A), R13.2
unnamed: D3.2 (A), R14.2
unnamed: D4.2 (A), R15.2

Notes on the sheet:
ESP32 3.3V Regulator
5V Power supply isolation
ADE9153A 3.3V Regulator

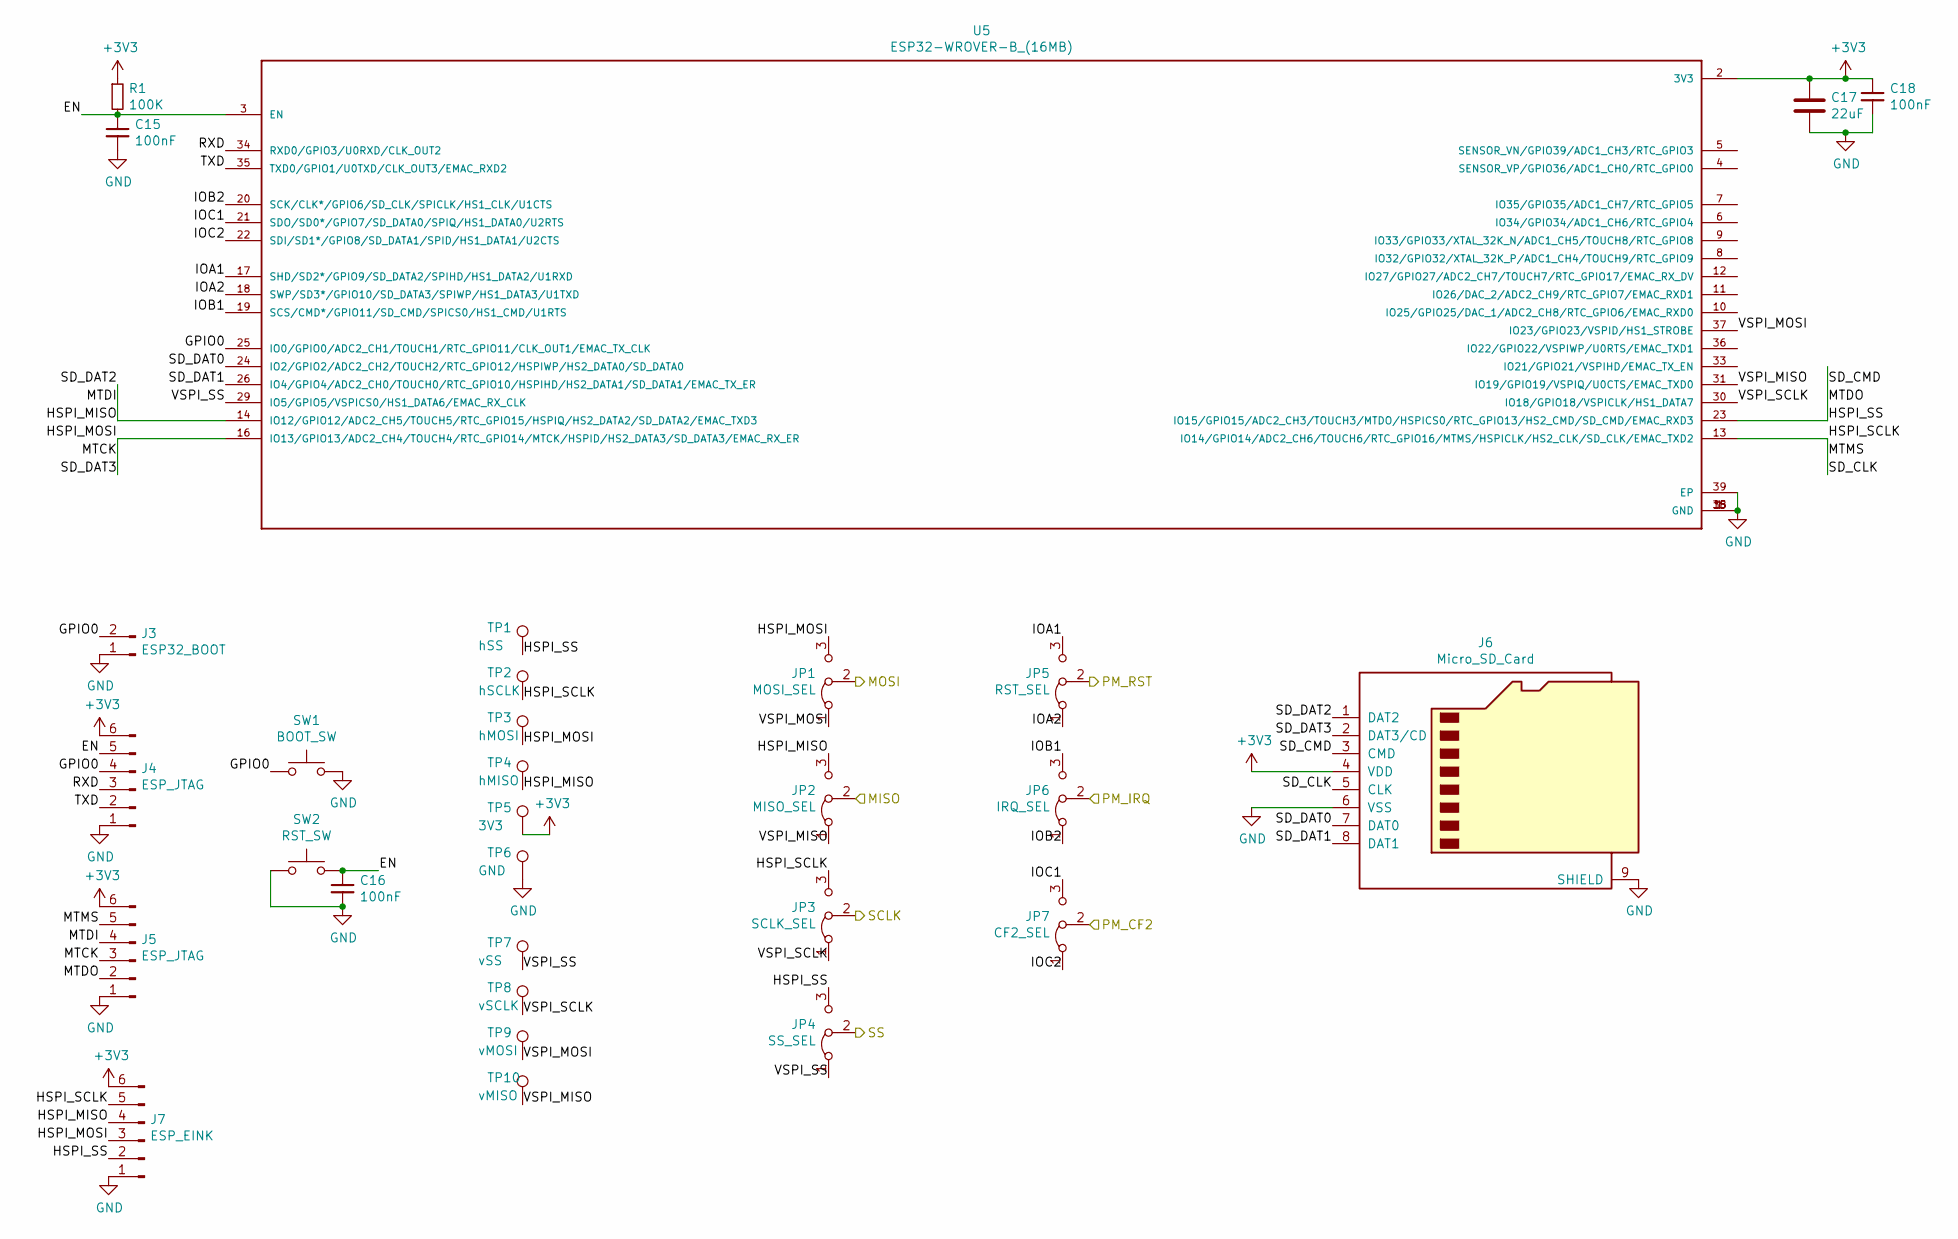
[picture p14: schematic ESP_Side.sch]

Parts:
C15, C16, C18: 100nF; C_0603_1608Metric
C17: 22uF; C_0603_1608Metric
J3: ESP32_BOOT; PinHeader_1x02_P2.54mm_Vertical
J4, J5: ESP_JTAG; JST_PH_B6B-PH-K_1x06_P2.00mm_Vertical
J6: Micro_SD_Card; microSD_HC_Hirose_DM3D-SF
J7: ESP_EINK; JST_PH_B6B-PH-K_1x06_P2.00mm_Vertical
JP1: MOSI_SEL; SolderJumper-3_P1.3mm_Bridged12_RoundedPad1.0x1.5mm_NumberL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
JP2: MISO_SEL; SolderJumper-3_P1.3mm_Bridged12_RoundedPad1.0x1.5mm_NumberL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
JP3: SCLK_SEL; SolderJumper-3_P1.3mm_Bridged12_RoundedPad1.0x1.5mm_NumberL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
JP4: SS_SEL; SolderJumper-3_P1.3mm_Bridged12_RoundedPad1.0x1.5mm_NumberL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
JP5: RST_SEL; SolderJumper-3_P1.3mm_Bridged12_RoundedPad1.0x1.5mm_NumberL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
JP6: IRQ_SEL; SolderJumper-3_P1.3mm_Bridged12_RoundedPad1.0x1.5mm_NumberL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
JP7: CF2_SEL; SolderJumper-3_P1.3mm_Bridged12_RoundedPad1.0x1.5mm_NumberL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
R1: 100K; R_0603_1608Metric
SW1: BOOT_SW; SW_PUSH_6mm
SW2: RST_SW; SW_PUSH_6mm
TP1: hSS; Pin_D1.0mm_L10.0mm
TP2: hSCLK; Pin_D1.0mm_L10.0mm
TP3: hMOSI; Pin_D1.0mm_L10.0mm
TP4: hMISO; Pin_D1.0mm_L10.0mm
TP5: 3V3; Pin_D1.0mm_L10.0mm
TP6: GND; Pin_D1.0mm_L10.0mm
TP7: vSS; Pin_D1.0mm_L10.0mm
TP8: vSCLK; Pin_D1.0mm_L10.0mm
TP9: vMOSI; Pin_D1.0mm_L10.0mm
TP10: vMISO; Pin_D1.0mm_L10.0mm
U5: ESP32-WROVER-B_(16MB); XCVR_ESP32-WROVER-B_(16MB)

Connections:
+3V3: C17.1, C18.1, J4.6, J5.6, J6.4 (VDD), J7.6, R1.1, TP5.1, U5.2 (3V3); also elsewhere on the board
/ESP Side/EN: C15.1, C16.1, J4.5, R1.2, SW2.2, U5.3 (EN)
/ESP Side/GPIO0: J3.2, J4.4, SW1.1, U5.25 (IO0/GPIO0/ADC2_CH1/TOUCH1/RTC_GPIO11/CL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)
/ESP Side/HSPI_MISO: J5.4, J6.1 (DAT2), J7.4, JP2.3 (B), TP4.1, U5.14 (IO12/GPIO12/ADC2_CH5/TOUCH5/RTC_GPIO15/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)
/ESP Side/HSPI_MOSI: J5.3, J6.2 (DAT3/CD), J7.3, JP1.3 (B), TP3.1, U5.16 (IO13/GPIO13/ADC2_CH4/TOUCH4/RTC_GPIO14/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)
/ESP Side/HSPI_SCLK: J5.5, J6.5 (CLK), J7.5, JP3.3 (B), TP2.1, U5.13 (IO14/GPIO14/ADC2_CH6/TOUCH6/RTC_GPIO16/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)
/ESP Side/HSPI_SS: J5.2, J6.3 (CMD), J7.2, JP4.3 (B), TP1.1, U5.23 (IO15/GPIO15/ADC2_CH3/TOUCH3/MTDO/HSPICS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)
/ESP Side/IOA1: JP5.3 (B), U5.17 (SHD/SD2*/GPIO9/SD_DATA2/SPIHD/HS1_DATA2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)
/ESP Side/IOA2: JP5.1 (A), U5.18 (SWP/SD3*/GPIO10/SD_DATA3/SPIWP/HS1_DATA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)
/ESP Side/IOB1: JP6.3 (B), U5.19 (SCS/CMD*/GPIO11/SD_CMD/SPICS0/HS1_CMD/U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)
/ESP Side/IOB2: JP6.1 (A), U5.20 (SCK/CLK*/GPIO6/SD_CLK/SPICLK/HS1_CLK/U1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)
/ESP Side/IOC1: JP7.3 (B), U5.21 (SDO/SD0*/GPIO7/SD_DATA0/SPIQ/HS1_DATA0/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)
/ESP Side/IOC2: JP7.1 (A), U5.22 (SDI/SD1*/GPIO8/SD_DATA1/SPID/HS1_DATA1/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)
/ESP Side/MISO: JP2.2 (C); also elsewhere on the board
/ESP Side/MOSI: JP1.2 (C); also elsewhere on the board
/ESP Side/PM_CF2: JP7.2 (C); also elsewhere on the board
/ESP Side/PM_IRQ: JP6.2 (C); also elsewhere on the board
/ESP Side/PM_RST: JP5.2 (C); also elsewhere on the board
/ESP Side/RXD: J4.3, U5.34 (RXD0/GPIO3/U0RXD/CLK_OUT2)
/ESP Side/SCLK: JP3.2 (C); also elsewhere on the board
/ESP Side/SD_DAT0: J6.7 (DAT0), U5.24 (IO2/GPIO2/ADC2_CH2/TOUCH2/RTC_GPIO12/HS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)
/ESP Side/SD_DAT1: J6.8 (DAT1), U5.26 (IO4/GPIO4/ADC2_CH0/TOUCH0/RTC_GPIO10/HS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)
/ESP Side/SS: JP4.2 (C); also elsewhere on the board
/ESP Side/TXD: J4.2, U5.35 (TXD0/GPIO1/U0TXD/CLK_OUT3/EMAC_RXD2)
/ESP Side/VSPI_MISO: JP2.1 (A), TP10.1, U5.31 (IO19/GPIO19/VSPIQ/U0CTS/EMAC_TXD0)
/ESP Side/VSPI_MOSI: JP1.1 (A), TP9.1, U5.37 (IO23/GPIO23/VSPID/HS1_STROBE)
/ESP Side/VSPI_SCLK: JP3.1 (A), TP8.1, U5.30 (IO18/GPIO18/VSPICLK/HS1_DATA7)
/ESP Side/VSPI_SS: JP4.1 (A), TP7.1, U5.29 (IO5/GPIO5/VSPICS0/HS1_DATA6/EMAC_RX_CLK)
GND: C15.2, C16.2, C17.2, C18.2, J3.1, J4.1, J5.1, J6.6 (VSS), J6.9 (SHIELD), J7.1, SW1.2, SW2.1, TP6.1, U5.1 (GND), U5.15 (GND), U5.38 (GND), U5.39 (EP); also elsewhere on the board

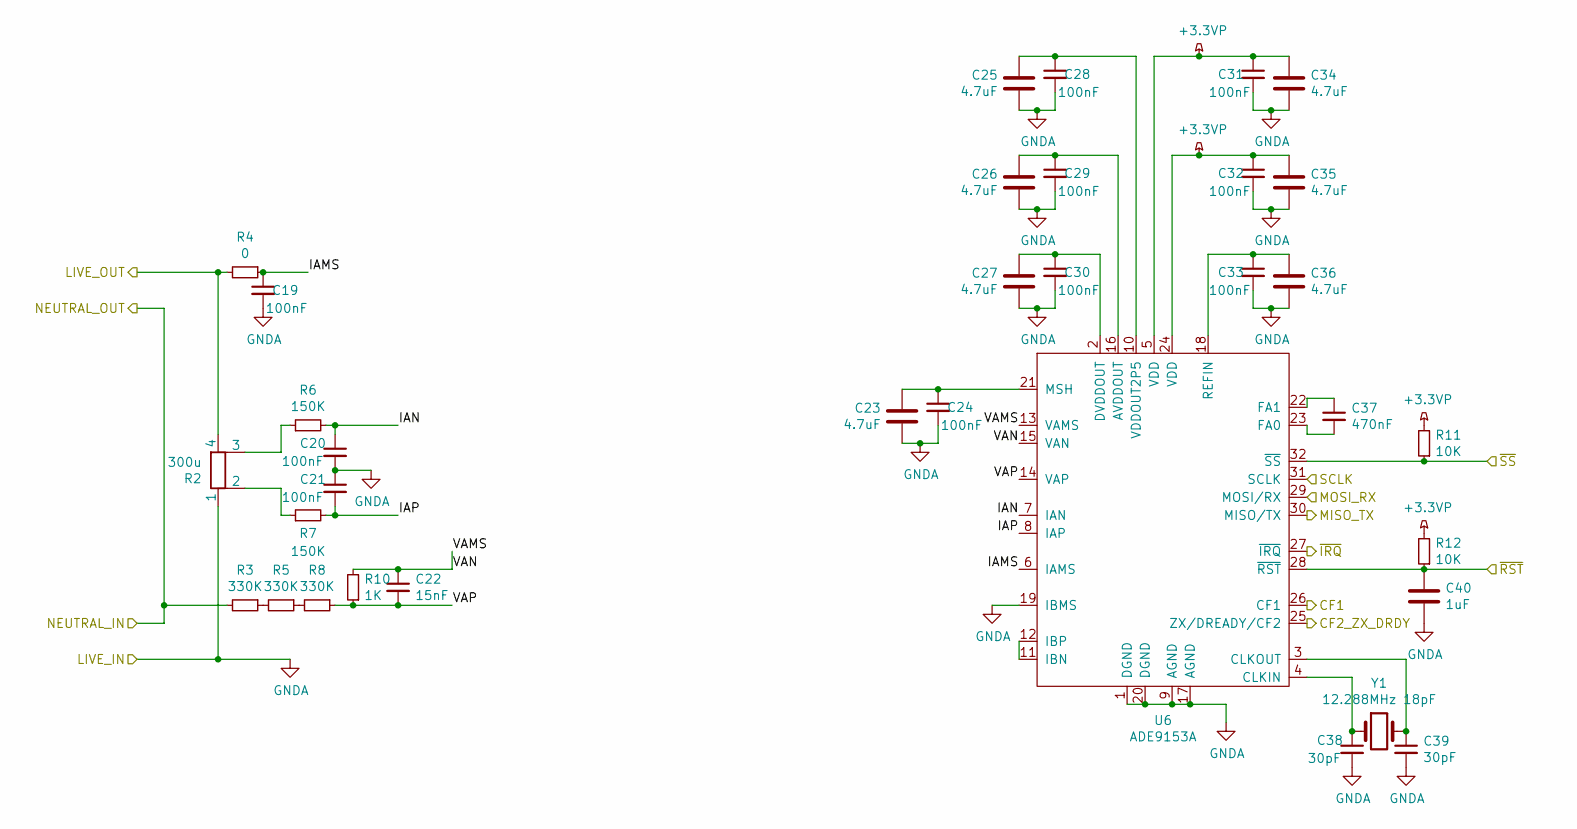
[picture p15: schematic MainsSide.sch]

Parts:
C19, C20, C21, C24, C28, C29, C30, C31, C32, C33: 100nF; C_0603_1608Metric
C22: 15nF; C_0603_1608Metric
C23, C25, C26, C27, C34, C35, C36: 4.7uF; C_0603_1608Metric
C37: 470nF; C_0603_1608Metric
C38, C39: 30pF; C_0603_1608Metric
C40: 1uF; C_0603_1608Metric
R2: 300u; WSL4026
R3, R5, R8: 330K; R_1206_3216Metric
R4: 0; R_0603_1608Metric
R6, R7: 150K; R_0603_1608Metric
R10: 1K; R_0603_1608Metric
R11, R12: 10K; R_0603_1608Metric
U6: ADE9153A; QFN-32-1EP_5x5mm_P0.5mm_EP3.1x3.1mm
Y1: 12.288MHz 18pF; Crystal_SMD_3225-4Pin_3.2x2.5mm

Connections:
+3.3VP: C31.1, C32.1, C34.1, C35.1, R11.2, R12.2, U6.5 (VDD), U6.24 (VDD); also elsewhere on the board
/Mains Side/CF1: U6.26 (CF1)
/Mains Side/CF2_ZX_DRDY: U6.25 (ZX/DREADY/CF2); also elsewhere on the board
/Mains Side/IAMS: C19.1, R4.1, U6.6 (IAMS)
/Mains Side/IAN: C20.1, R6.2, U6.7 (IAN)
/Mains Side/IAP: C21.2, R7.2, U6.8 (IAP)
/Mains Side/LIVE_OUT: R2.4, R4.2; also elsewhere on the board
/Mains Side/MISO_TX: U6.30 (MISO/TX); also elsewhere on the board
/Mains Side/MOSI_RX: U6.29 (MOSI/RX); also elsewhere on the board
/Mains Side/NEUTRAL_IN: R3.2; also elsewhere on the board
/Mains Side/SCLK: U6.31 (SCLK); also elsewhere on the board
/Mains Side/VAMS: C22.1, R10.2, U6.13 (VAMS), U6.15 (VAN)
/Mains Side/VAP: C22.2, R8.1, R10.1, U6.14 (VAP)
/Mains Side/~IRQ: U6.27 (~IRQ); also elsewhere on the board
/Mains Side/~RST: C40.1, R12.1, U6.28 (~RST); also elsewhere on the board
/Mains Side/~SS: R11.1, U6.32 (~SS); also elsewhere on the board
GNDA: C19.2, C20.2, C21.1, C23.2, C24.2, C25.2, C26.2, C27.2, C28.2, C29.2, C30.2, C31.2, C32.2, C33.2, C34.2, C35.2, C36.2, C38.2, C39.2, C40.2, R2.1, U6.1 (DGND), U6.9 (AGND), U6.17 (AGND), U6.19 (IBMS), U6.20 (DGND); also elsewhere on the board
unnamed: C23.1, C24.1, U6.21 (MSH)
unnamed: C25.1, C28.1, U6.10 (VDDOUT2P5)
unnamed: C26.1, C29.1, U6.16 (AVDDOUT)
unnamed: C27.1, C30.1, U6.2 (DVDDOUT)
unnamed: C33.1, C36.1, U6.18 (REFIN)
unnamed: C37.1, U6.22 (FA1)
unnamed: C37.2, U6.23 (FA0)
unnamed: C38.1, U6.4 (CLKIN), Y1.1
unnamed: C39.1, U6.3 (CLKOUT), Y1.2
unnamed: R2.2, R7.1
unnamed: R2.3, R6.1
unnamed: R3.1, R5.2
unnamed: R5.1, R8.2
unnamed: U6.11 (IBN), U6.12 (IBP)

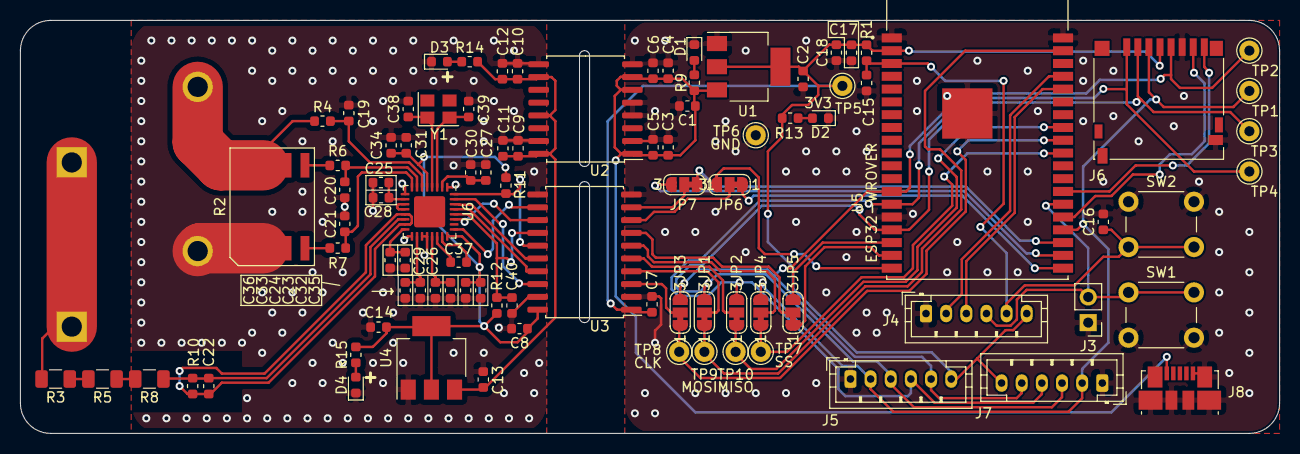
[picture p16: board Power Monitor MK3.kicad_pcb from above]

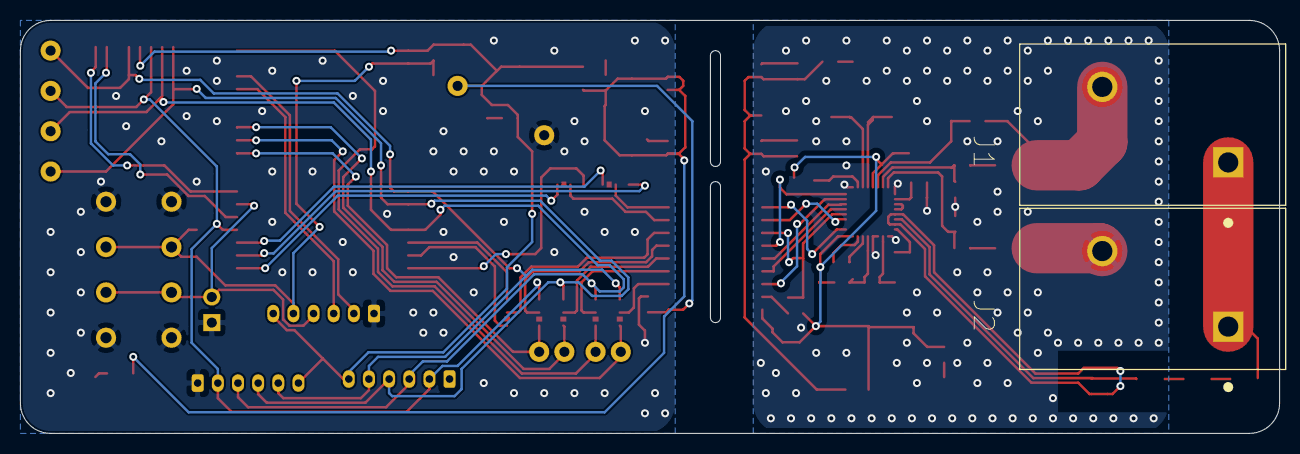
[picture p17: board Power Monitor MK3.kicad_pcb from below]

Board: 2 copper layers, 125.0 x 41.0 mm, 93 parts (2 on the bottom side), 65 nets.

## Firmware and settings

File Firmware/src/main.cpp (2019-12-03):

#include <WiFi.h>
#include "../include/ota.h"
#include "../include/aws.h"
#include <SPI.h>
#include "../lib/ADE9153A/ADE9153A.h"
#include "../lib/ADE9153A/ADE9153AAPI.h"

#include "../include/secrets.h"

#define PM_RST 32 /* Pin 8 */
#define PM_IRQ 33 /* Pin 9 */
#define PM_CF2 27 /* Pin 12 */
#define PM_SS 5 /* Pin 29 */
#define SPI_MISO 19 /* VSPI Pin 31 */
#define SPI_MOSI 23 /* VSPI Pin 37 */
#define SPI_SCLK 18 /* VSPI Pin 30 */


#define SPI_SPEED 1000000     //SPI Speed

ADE9153AClass ade9153A;

struct EnergyRegs energyVals;
struct PowerRegs powerVals;
struct RMSRegs rmsVals;  
struct PQRegs pqVals;
struct AcalRegs acalVals;
struct Temperature tempVal;

unsigned long lastReport = 0;
const long reportInterval = 2000;

void readandwrite(void);

void setup() {
  Serial.begin(115200);
  Serial.println("Booting");
  WiFi.mode(WIFI_STA);
  WiFi.begin(WIFI_SSID, WIFI_PASS);
  while (WiFi.waitForConnectResult() != WL_CONNECTED) {
    Serial.println("Connection Failed! Rebooting...");
    delay(5000);
    ESP.restart();
  }

  Serial.println("Ready");
  Serial.print("IP address: ");
  Serial.println(WiFi.localIP());
  ota_configure();

  xTaskCreate(
    ota_task,               /* Task function. */
    "OTA_TASK",             /* String with name of task. */
    10000,                  /* Stack size in bytes. */
    NULL,                   /* Parameter passed as input of the task */
    1,                      /* Priority of the task. */
    NULL);                  /* Task handle. */

  xTaskCreatePinnedToCore(
    &aws_shadow_update_task,/* Task function. */
    "aws_iot_task",         /* String with name of task. */
    9216,                   /* Stack size in bytes. */
    NULL,                   /* Parameter passed as input of the task */
    5,                      /* Priority of the task. */
    NULL,                   /* Task handle. */
    1);                     /* The core to run the task on */


  pinMode(PM_SS, OUTPUT);
  pinMode(PM_RST, OUTPUT);
  pinMode(SPI_SCLK, OUTPUT);
  digitalWrite(PM_SS, LOW);
  digitalWrite(SPI_SCLK, HIGH);

  
  digitalWrite(PM_RST, LOW);
  delay(100);
  digitalWrite(PM_RST, HIGH);
  delay(1000);

  delay(1000);
  /*SPI initialization and test*/
  bool commscheck = ade9153A.SPI_Init(SPI_SPEED, PM_SS); //Initialize SPI
  if (!commscheck) {
    Serial.println("ADE9153A Shield not detected. Plug in Shield and reset the Arduino");
    while (!commscheck) {     //Hold until arduino is reset
      delay(1000);
    }
  }
  
  ade9153A.SetupADE9153A(); //Setup ADE9153A according to ADE9153AAPI.h
  /* Read and Print Specific Register using ADE9153A SPI Library */
  Serial.println(String(ade9153A.SPI_Read_32(REG_VERSION_PRODUCT), HEX)); // Version of IC
  ade9153A.SPI_Write_32(REG_AIGAIN, -268435456); //AIGAIN to -1 to account for IAP-IAN swap
  delay(500); 
  return;
}

void loop() 
{
  unsigned long currentReport = millis();
  
  if ((currentReport - lastReport) >= reportInterval){
    lastReport = currentReport;
    readandwrite();
  }
}

void readandwrite()
{ 
 /* Read and Print WATT Register using ADE9153A Read Library */
  ade9153A.ReadPowerRegs(&powerVals);    //Template to read Power registers from ADE9000 and store data in Arduino MCU
  ade9153A.ReadRMSRegs(&rmsVals);
  ade9153A.ReadPQRegs(&pqVals);
  ade9153A.ReadTemperature(&tempVal);
  
  Serial.printf("RMS Current:\t%.3f A\n\r", rmsVals.CurrentRMSValue/1000);
  Serial.printf("RMS Voltage:\t%.3f V\n\r", rmsVals.VoltageRMSValue/1000);
  
  Serial.print("Active Power:\t");        
  Serial.print(powerVals.ActivePowerValue/1000);
  Serial.println(" W");
  
  Serial.print("Reactive Power:\t");        
  Serial.print(powerVals.FundReactivePowerValue/1000);
  Serial.println(" VAR");
  
  Serial.print("Apparent Power:\t");        
  Serial.print(powerVals.ApparentPowerValue/1000);
  Serial.println(" VA");
  
  Serial.print("Power Factor:\t");        
  Serial.println(pqVals.PowerFactorValue);
  
  Serial.print("Frequency:\t");        
  Serial.print(pqVals.FrequencyValue);
  Serial.println(" Hz");
  
  Serial.print("Temperature:\t");        
  Serial.print(tempVal.TemperatureVal);
  Serial.println(" degC");

  Serial.println("");
  Serial.println("");
}

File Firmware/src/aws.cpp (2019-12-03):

#include <stdio.h>
#include <stdlib.h>
#include <ctype.h>
#include <unistd.h>
#include <limits.h>
#include <string.h>

#include "esp_log.h"

#include "aws.h"
#include "wifi.h"
#include <WiFiClientSecure.h>
#include <MQTTClient.h>
#include <ArduinoJson.h>

#include "../include/secrets.h"

extern const char aws_root_ca_pem_start[] asm("_binary_cert_aws_root_ca_pem_start");
extern const uint8_t aws_root_ca_pem_end[] asm("_binary_cert_aws_root_ca_pem_end");
extern const char certificate_pem_crt_start[] asm("_binary_cert_certificate_pem_crt_start");
extern const uint8_t certificate_pem_crt_end[] asm("_binary_cert_certificate_pem_crt_end");
extern const char private_pem_key_start[] asm("_binary_cert_private_pem_key_start");
extern const uint8_t private_pem_key_end[] asm("_binary_cert_private_pem_key_end");


// The MQTTT endpoint for the device (unique for each AWS account but shared amongst devices within the account)
#define AWS_IOT_ENDPOINT AWS_URL_PREFIX ".iot.eu-west-1.amazonaws.com"

// The MQTT topic that this device should publish to
#define AWS_IOT_TOPIC "$aws/things/" DEVICE_NAME "/shadow/update"

// How many times we should attempt to connect to AWS
#define AWS_MAX_RECONNECT_TRIES 50

WiFiClientSecure net = WiFiClientSecure();
MQTTClient client = MQTTClient(512);


void connect_to_aws(void)
{
    
    net.setCACert(aws_root_ca_pem_start);
    net.setCertificate(certificate_pem_crt_start);
    net.setPrivateKey(private_pem_key_start);
    client.begin(AWS_IOT_ENDPOINT, 8883, net);

        int retries = 0;
    Serial.print("Connecting to AWS IOT");

    while (!client.connect(DEVICE_NAME) && retries < AWS_MAX_RECONNECT_TRIES) {
        Serial.print(".");
        delay(100);
        retries++;
    }

    // Make sure that we did indeed successfully connect to the MQTT broker
    // If not we just end the function and wait for the next loop.
    if(!client.connected()){
        Serial.println(" Timeout!");
        return;
    }

    // If we land here, we have successfully connected to AWS!
    // And we can subscribe to topics and send messages.
    Serial.println("Connected!");
}

void sendJsonToAWS()
{
    StaticJsonDocument<512> jsonDoc;
    JsonObject stateObj = jsonDoc.createNestedObject("state");
    JsonObject reportedObj = stateObj.createNestedObject("reported");


    reportedObj["device_IP"] = WiFi.localIP().toString();

    // Create a nested object "location"
    JsonObject locationObj = reportedObj.createNestedObject("wifi");
    locationObj["wifi_SSID"] = WiFi.SSID();
    locationObj["wifi_strength"] = WiFi.RSSI();
  
    char buffer[512];
    serializeJson(jsonDoc, buffer);

    Serial.print(buffer);
    Serial.print(" => ");
    Serial.println(AWS_IOT_TOPIC);
    // Publish the message to AWS
    client.publish(AWS_IOT_TOPIC, buffer);
}

void aws_shadow_update_task(void *param)
{
    connect_to_aws();
    while(1)
    {
        sendJsonToAWS();
        vTaskDelay(30000/portTICK_RATE_MS);
    }
    vTaskDelete( NULL );
}

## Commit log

2019-06-02 Respec'd digikey parts to Mouser due to price
    Digikey lost the price war on all parts and charged a large import charge to get them in the UK, Mouser is proving a much more sensible supplier for me.
    [BOM.ods]
2019-06-02 Refactored project
    [Power Monitor MK3.kicad_pcb, Power Monitor MK3.sch]
2019-06-02 Moved PCB files into folder
    [BOM.ods, ESP_Side.sch, MainsSide.sch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]
2019-06-02 Added Gerbers and PDF's ISS1
    [Power Monitor MK3-B_Cu.gbr, Power Monitor MK3-B_Mask.gbr, Power Monitor MK3-B_Paste.gbr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]
2019-12-02 First stage initial FW, based on analog devices ADE9153A library, rewrite pending.
    Supports Arduino OTA and AWS shadow
2019-12-03 Updated ADE CC values as per recent appnote revelations, data looking better, still not sure about the power values. Need to get auto calibration going next
